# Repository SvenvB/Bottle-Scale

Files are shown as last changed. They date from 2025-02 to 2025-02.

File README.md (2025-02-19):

# BabyBuddy Bottle Scale for Home Assistant
Bottle scale for timing and weighing baby food. The scale is integrated with the Baby Buddy integration in Home Assistant.

* The scale design is inspired by the great work from [sfgabe:](https://github.com/sfgabe/OITProjects/tree/master/BabyBuddy_ESP_HASS), but since I am by far not a woodworking expert, I designed a similar casing in FreeCAD that can be 3D printed. Attached are the files.
* The scale is connected to HomeAssistant via [ESPHome](https://www.home-assistant.io/integrations/esphome/)
* The scale automation is integrated with the NodeRED BabyBuddy project of [tango259](https://github.com/tango2590/baby-buddy)

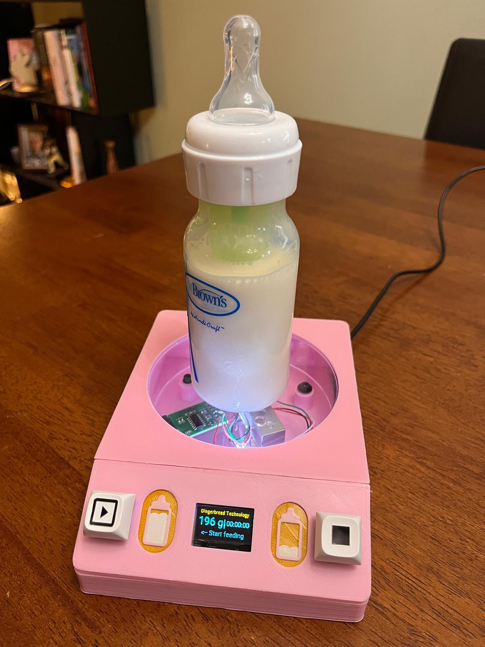
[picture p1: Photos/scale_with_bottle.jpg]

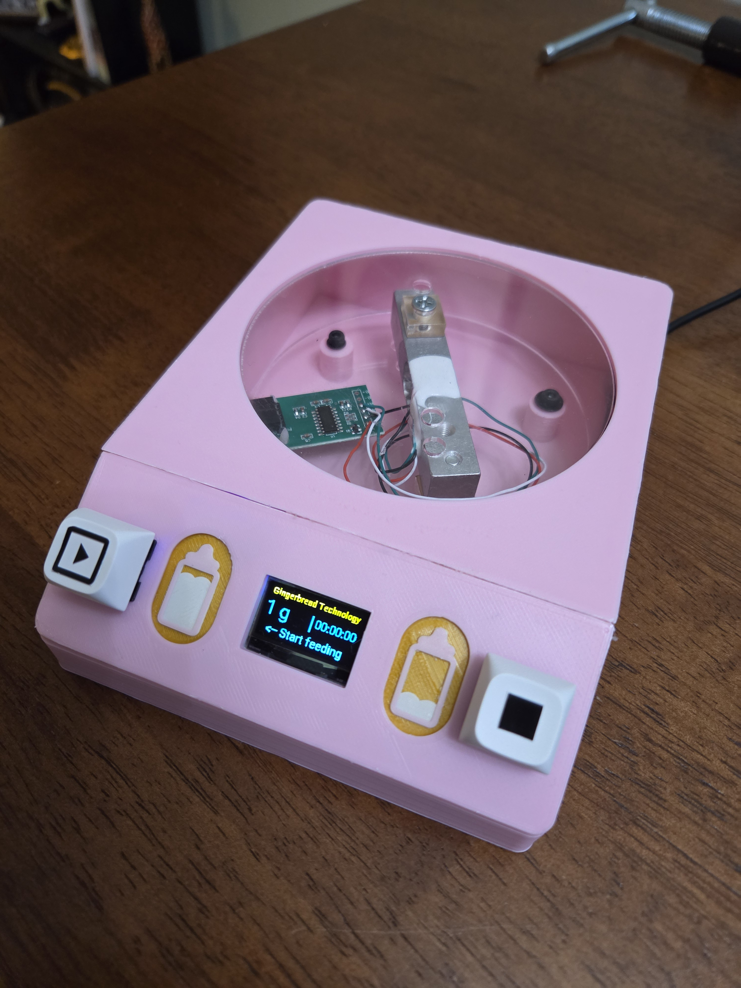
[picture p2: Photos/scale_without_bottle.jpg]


## Ingredients
* 1x [Strain gauge load cell with HX711 amplifier / AD converter](https://www.aliexpress.us/item/3256807921661482.html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). I used a 1 kg capacity load cell, but 5 kg should work also. 
* 1x [Lolin NodeMCU v3 ESP8266 with integrated 0.96" SSD1306 screen](https://www.aliexpress.us/item/3256806790582188.html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). Screen could be bought and connected separately to the microcontroller.
* 2x [Blank Keypad Buttons](https://www.aliexpress.us/item/3256807496928162.html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)
* 2x [Mechanical keyboard switches](https://www.aliexpress.us/item/3256807318817256.html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)
* 3x 5mm through hole LEDs of different colors
* 3x through hole resistors of ~50 Ohm
* (2x M2 screws to fix the microcontroller in the box)
* (3x M3 screws to fix the weighing scale to the box)

## Electrical Connections
* The ESP8266 is getting power from the Vin + GND pins via a USB cable that has a soldered [2x1 female pin header](https://github.com/SvenvB/Bottle-Scale/blob/main/Photos/usb-cable.jpg) to connect to those pins. Using the USB-C connection on the board is not possible because the space is blocked by the push buttons in this CAD design.
* The D8 pin has an internal pull-down resistor, and D8 must be low at boot to avoid boot failure. Therefore, the button connected to D8 should be connected to the +3.3V pin, and not GND. The button connected to D7 makes use of an internal pull-up resistor and is therefore connected to GND.
* The D5 and D6 pins are used by the onboard SSD1306 screen.

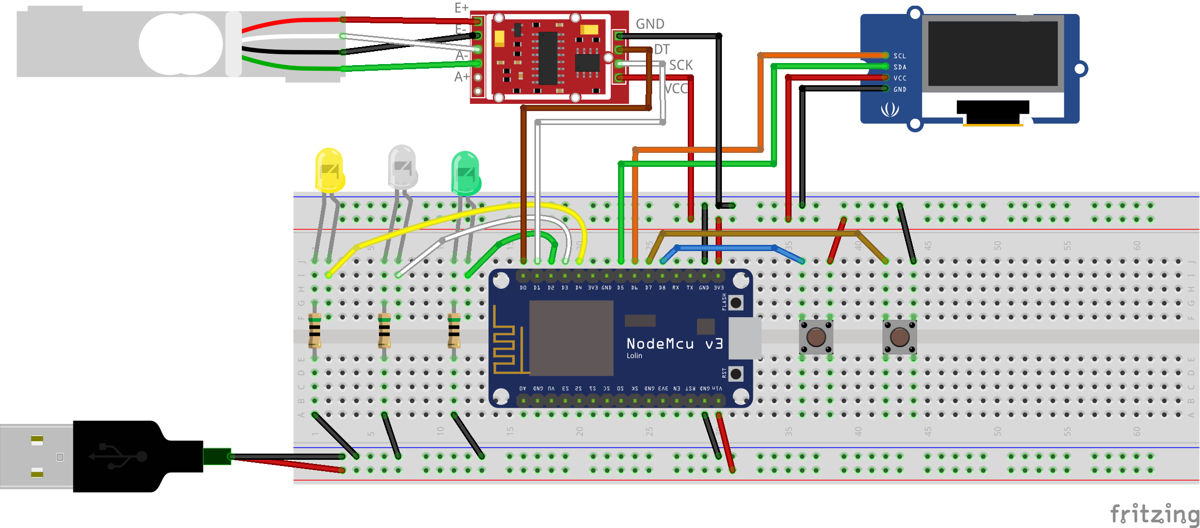
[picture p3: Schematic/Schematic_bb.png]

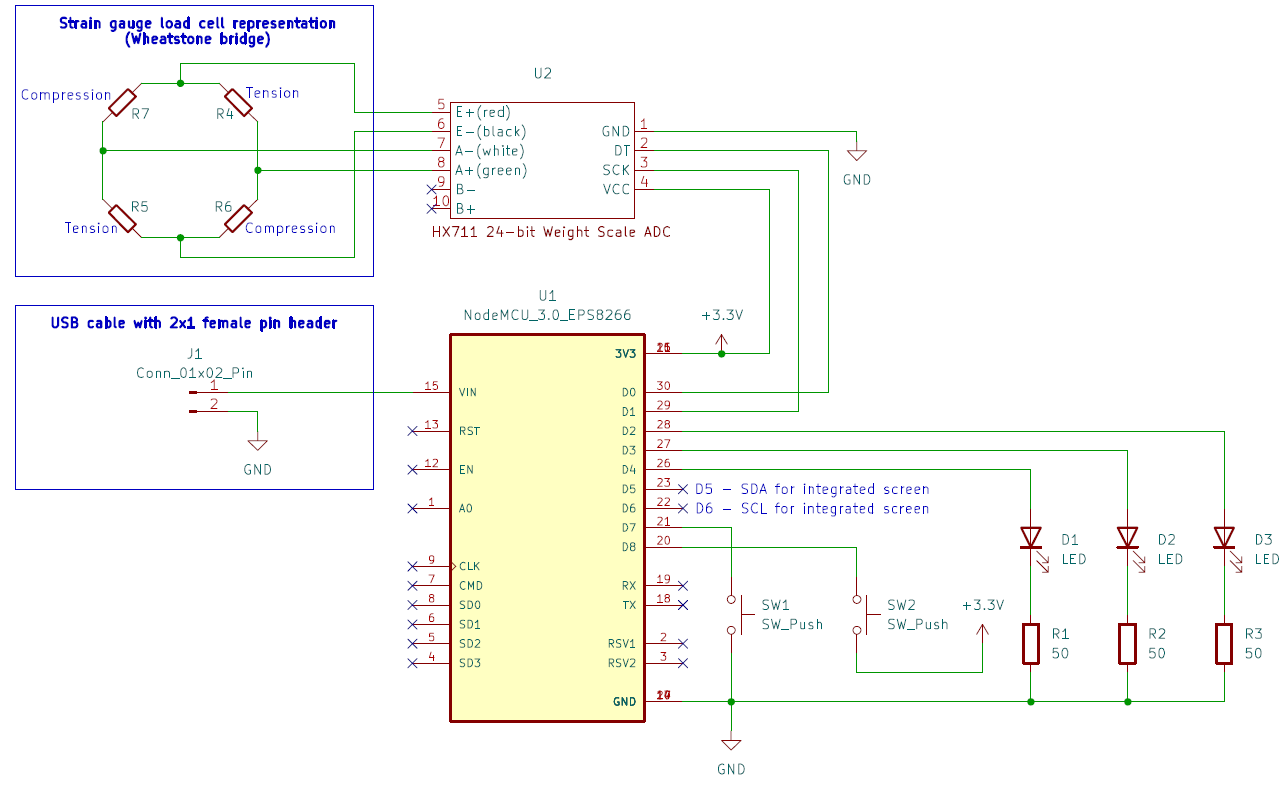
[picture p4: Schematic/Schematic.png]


* The load cell is connected to the HX711 breakout board using 4-wires. Take a moment to familiarize yourself with the basic principle of how a single-point load cell [works](https://www.800loadcel.com/blog/single-point-load-cells-what-they-are-and-how-they-work.html). It relies on 4x strain gauges in a Wheatstone bridge configuration as indicated in the [schematic](https://github.com/SvenvB/Bottle-Scale/blob/main/Schematic/Schematic.png) above. The resistance of those gauges depends on the tension (of the 2x gauges on top) and compression (of the 2x gauges on the bottom) due to the weight applied to the aluminum. Two wires (red [E+] & black [E-]) are used to bias the bridge, whereas the signal potential (Vsignal = [A+] - [A-]) grows with increasing contrast between the tension and compression resistances. The signal is amplified and digitized by the HX711 breakout board. No more to it than that.

## CAD Modeling
* The scale is designed in freeware [FreeCAD](https://www.freecad.org/). Uploaded are the step files but also the FreeCAD project so you can make any changes desired:

**Important notes:**
* The screen location might differ since the screen is manually attached to the board using double-sided tape. Therefore you might need to adjust the CAD model based on your screen location.
* Similarly the mounting holes in the plastic plates of the bottle scale seem to be manually drilled. This also might warrant some manual changes in the CAD model so that your scale fits. The hole in the top plate is a tight fit.
* The electronics compartment is also quite compact. You will want to remove any excessive wire length otherwise it won't fit.
* The top plate and computer plate are not screwed down but glued using a glue pistol. If you don't have a glue pistol or strong double-sided tape, you might want to add some screw holes in the design.   

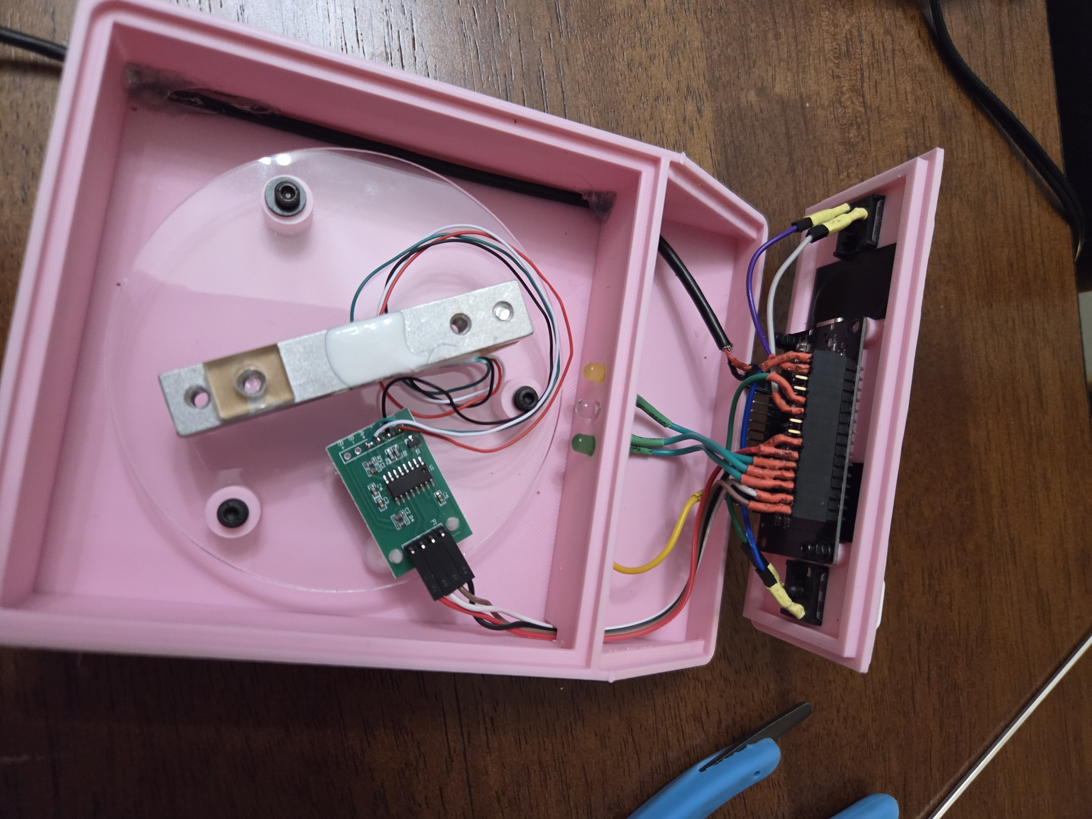
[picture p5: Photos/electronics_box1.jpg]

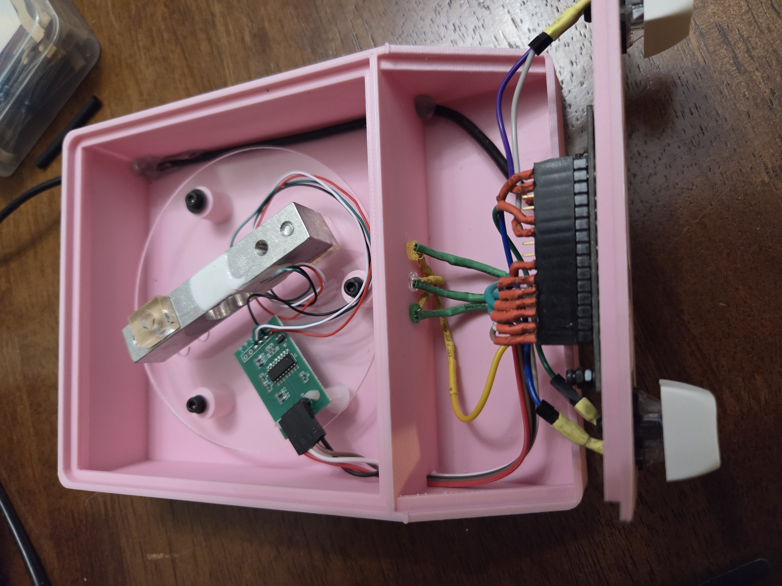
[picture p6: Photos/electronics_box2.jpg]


* The buttons are printed on a 4x6" photo at the local CVS store:

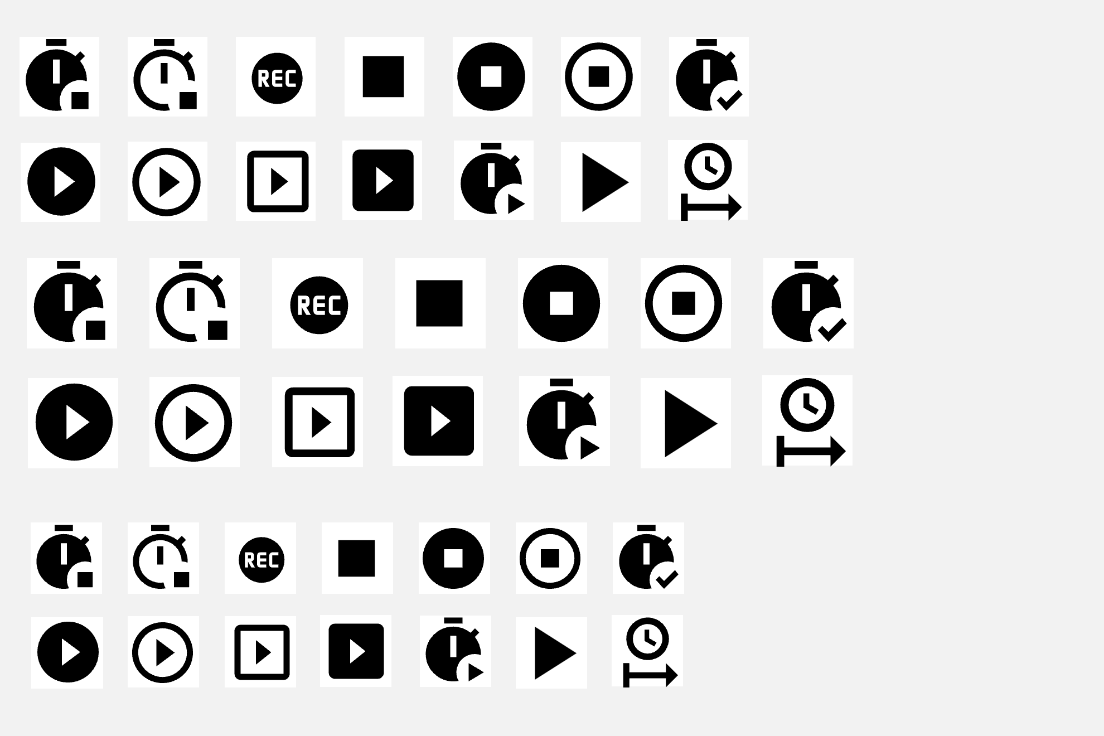
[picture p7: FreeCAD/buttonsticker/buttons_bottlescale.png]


## ESPHome and Automation
I won't go into much detail here, as this can be integrated however you like and I assume that you already have set up BabyBuddy in HomeAssistant. I integrated the automation directly with the NodeRED BabyBuddy project of [tango259](https://github.com/tango2590/baby-buddy).

Attached you can find my [ESPHome code](https://github.com/SvenvB/Bottle-Scale/blob/main/esphome_code.yaml) for the device. The microcontroller receives one sensor and two text_sensors from the home assistant front-end:
* *input_number.bottle_scale_calibration_value*: which is the measured weight when pushing the start button on the left-hand-side. It then subtracts this calibration value from the measured value so that when you put the empty bottle on the scale to stop recording, you can directly see how much the baby ate.
* *sensor.stopwatch*: is the [stopwatch](https://community.home-assistant.io/t/stopwatch-with-start-stop-resume-lap-and-reset/443994) used in the NodeRED BabyBuddy project of [tango259](https://github.com/tango2590/baby-buddy). The stopwatch value is also shown on the screen.
* *input_text.bottle_scale_status*: is a text label on the bottom of the screen that either says *<-- Start feeding*, *Stop feeding-->*, or *Feeding recorded!*.

Don't forget to [calibrate](https://esphome.io/components/sensor/hx711.html) your scale in ESPhome code by removing my calibration and then find the sensor readings when using zero load and a known weight. 

Happy feeding!

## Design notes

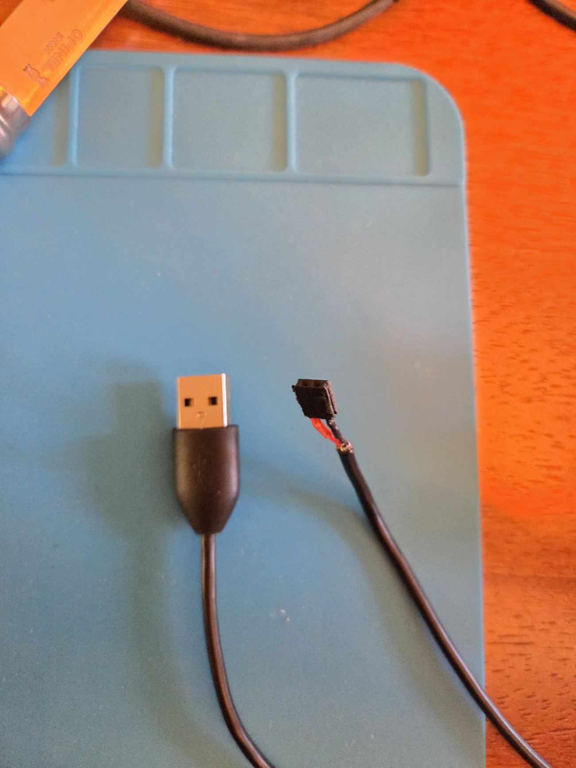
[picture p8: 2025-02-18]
Photos/usb-cable.jpg

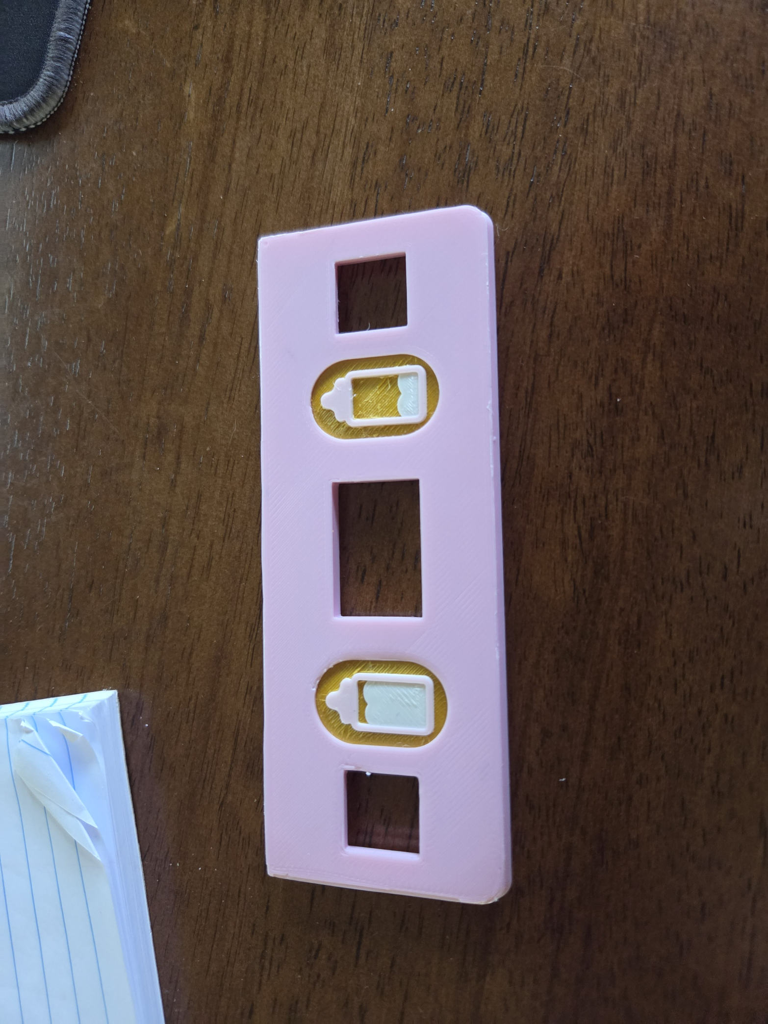
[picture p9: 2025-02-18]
Photos/computer_plate_front.jpg

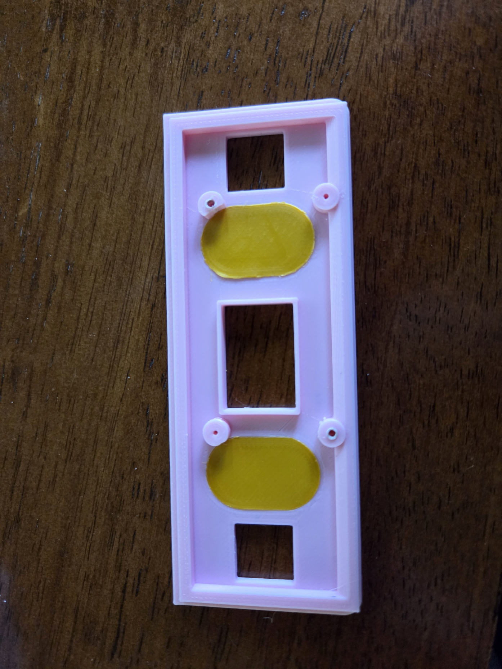
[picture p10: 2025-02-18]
Photos/computer_plate_back.jpg

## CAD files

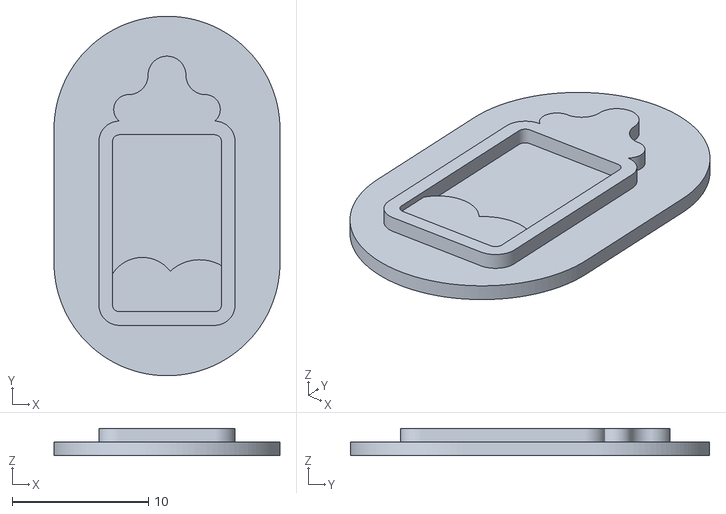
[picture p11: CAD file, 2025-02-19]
FreeCAD/BottleScale-Box AssemblyEmpty bottle.stl
16.6 x 26.4 x 2.00

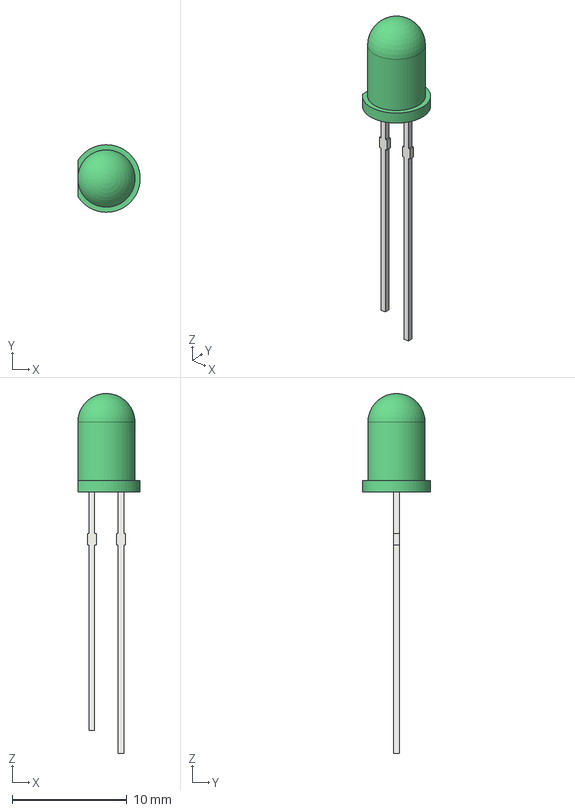
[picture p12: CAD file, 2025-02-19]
FreeCAD/Green Detailed 5mm LED.step
5.45 x 5.90 x 31.4 mm
Glass Round 5mm003
Pin Two MKIII
Pin One MKIII
Bond Wire011

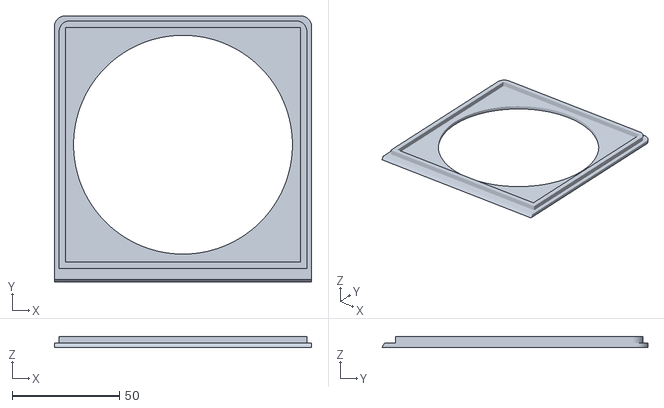
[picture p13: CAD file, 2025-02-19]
FreeCAD/BottleScale-Top plateBody001.stl
120.0 x 124.0 x 5.00

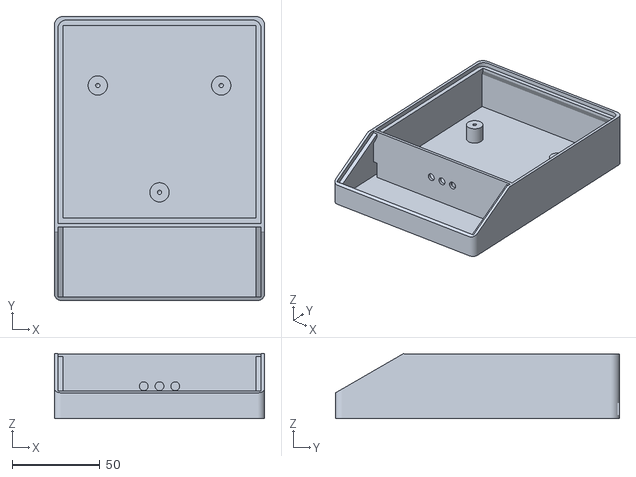
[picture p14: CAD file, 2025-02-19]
FreeCAD/BottleScale-Box.stl
120.0 x 162.0 x 37.2

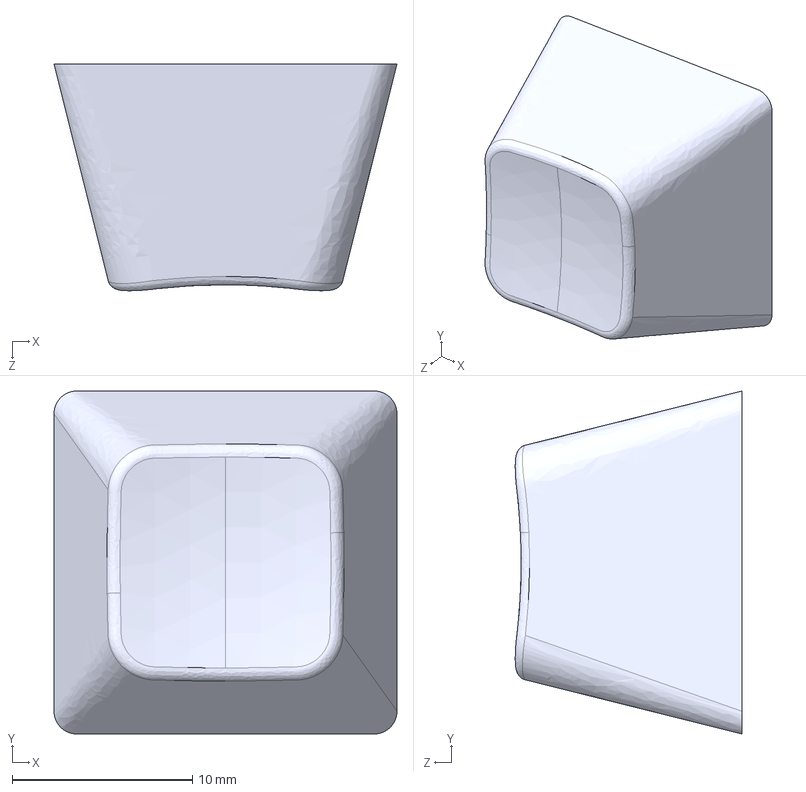
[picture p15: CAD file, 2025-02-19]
FreeCAD/keycap_dsa_signatureplastics_r3.STEP
19.1 x 19.1 x 12.6 mm

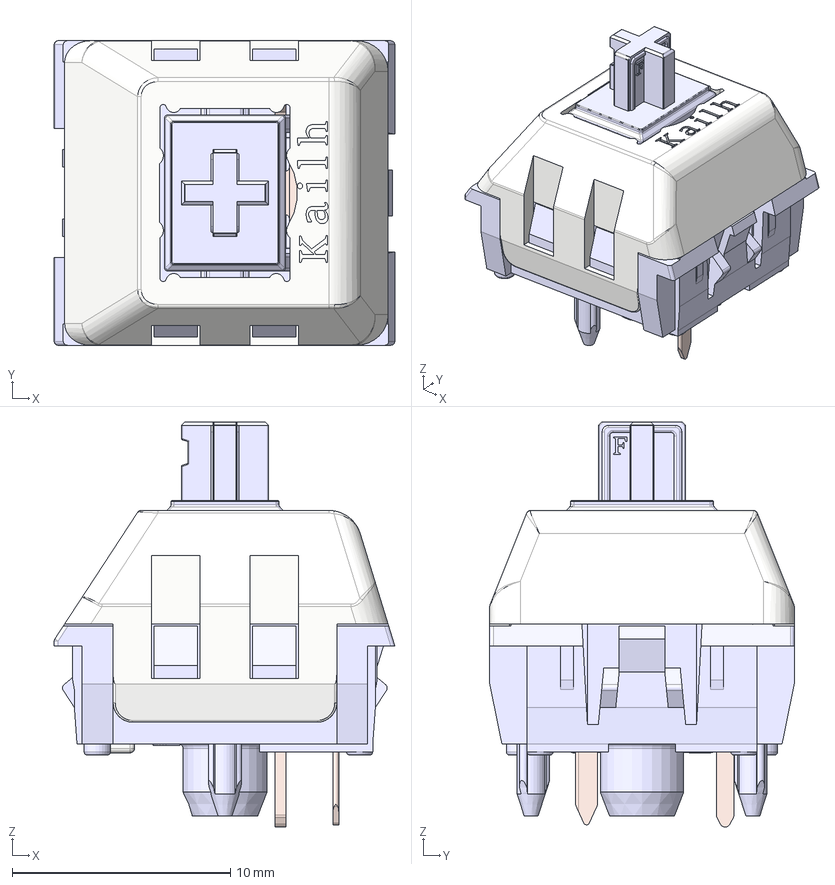
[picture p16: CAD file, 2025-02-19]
FreeCAD/pushbutton.step
15.6 x 14.0 x 18.5 mm
Housing
ThickContact
SpringContact
Stem
Lid

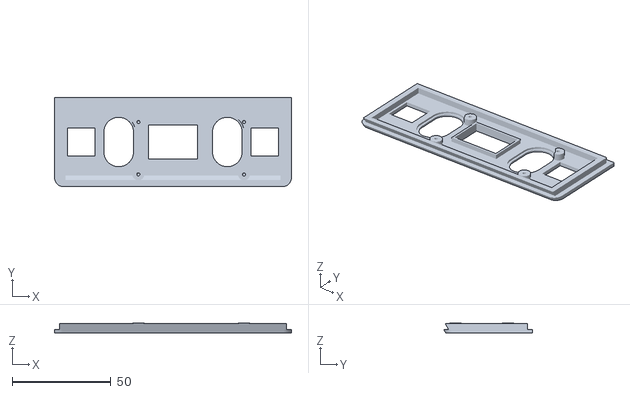
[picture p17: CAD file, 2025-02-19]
FreeCAD/BottleScale-Computer_plate.stl
120.0 x 45.0 x 5.30

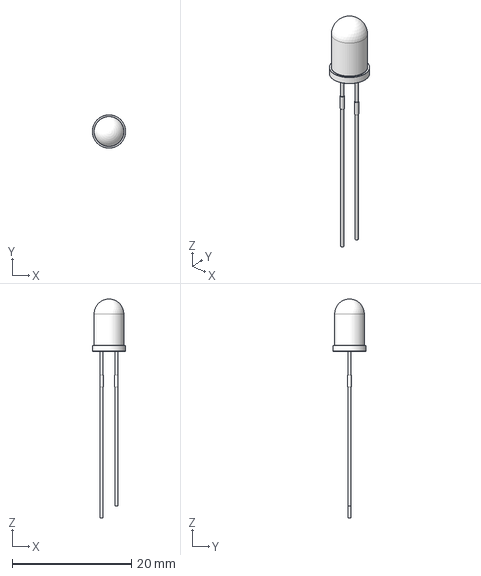
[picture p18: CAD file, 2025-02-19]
FreeCAD/STEP_LED_DIODE_5mm.step
5.59 x 5.60 x 36.8 mm

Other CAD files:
FreeCAD/BottleScale-Box AssemblyFull bottle.stl
FreeCAD/Red Detailed 5mm LED.step

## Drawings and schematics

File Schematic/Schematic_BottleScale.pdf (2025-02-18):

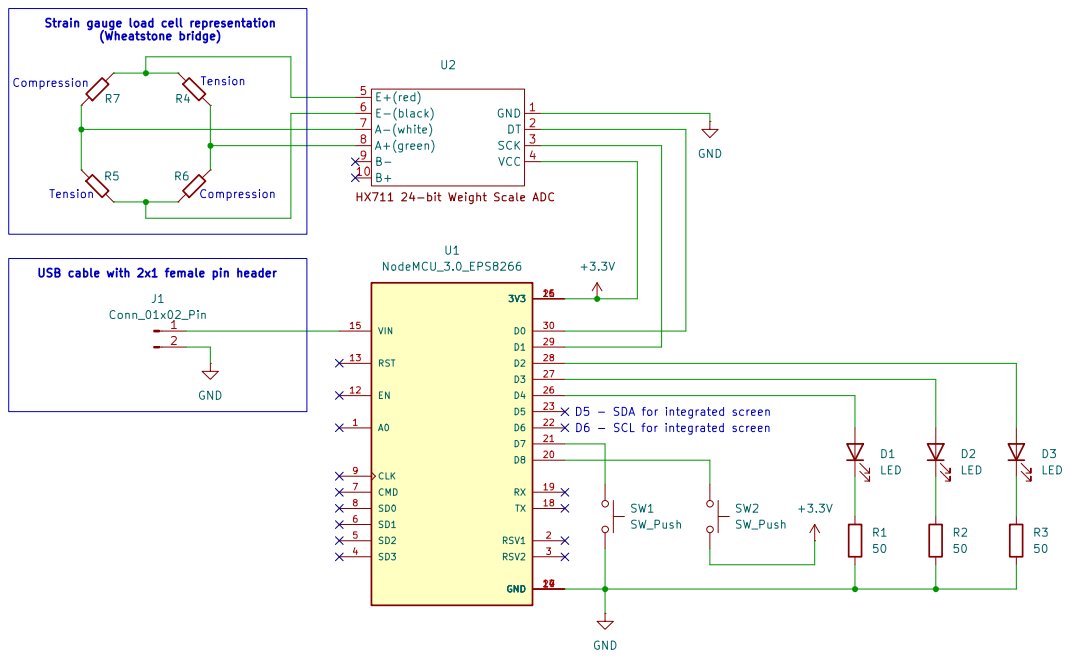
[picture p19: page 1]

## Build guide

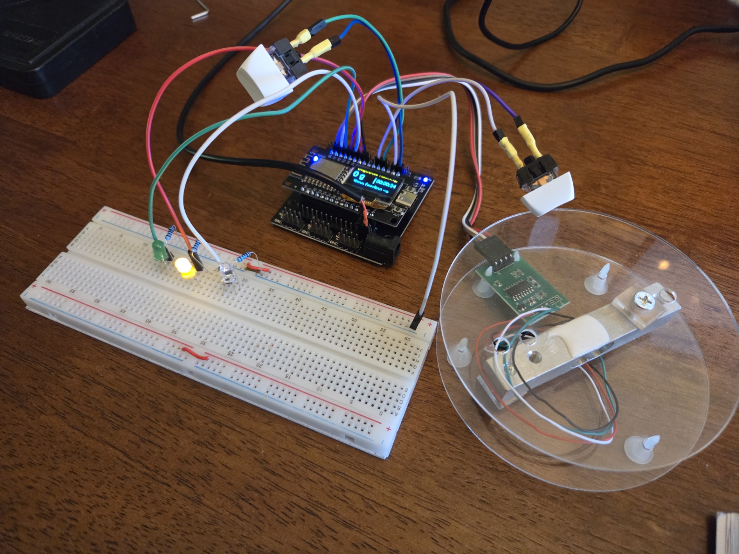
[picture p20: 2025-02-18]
Photos/breadboard_setup.jpg

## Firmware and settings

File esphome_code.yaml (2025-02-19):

esphome:
  name: bottle-scale
  friendly_name: Bottle Scale

esp8266:
  board: nodemcuv2

# Enable logging
logger:
  level: DEBUG  # Keep debug for other components
  logs:
    hx711: WARN  # Suppress detailed HX711 messages

# Enable Home Assistant API
api:
  encryption:
    key: YOURAPIKEY

ota:
  - platform: esphome
    password: YOUROTAPASS

wifi:
  ssid: !secret wifi_ssid
  password: !secret wifi_password

  # Enable fallback hotspot (captive portal) in case wifi connection fails
  ap:
    ssid: "Bottle-Scale Fallback Hotspot"
    password: PASS

captive_portal:

# Status LEDs
switch:
  - platform: gpio
    pin: D2
    name: "Bottle scale status LED - Green"
    id: LED_green
  - platform: gpio
    pin: D4
    name: "Bottle scale status LED - Yellow"
    id: LED_yellow
  - platform: gpio
    pin: D3
    name: "Bottle scale status LED - White"
    id: LED_white        

# Font definitions
font:
  - file: "gfonts://Roboto"
    id: title_font
    size: 11
  - file: "gfonts://Roboto"
    id: meas_font
    size: 25
  - file: "gfonts://Roboto"
    id: time_font
    size: 15    
# I2C Configuration for HW364A OLED
i2c:
  sda: D5
  scl: D6
  scan: true # Enable to detect I2C devices
  frequency: 400kHz

# OLED Display Configuration
display:
  - platform: ssd1306_i2c
    model: "SSD1306 128X64"
    address: 0x3C
    id: hw364a_display
    pages:
      - id: page1
        lambda: |-
          // Print "Gingerbread Technology" on the first line, centered
          const char *title = "Gingerbread Technology";
          int title_width = strlen(title) * 5.5;  // Estimate character width (adjust if needed)
          int title_x = (128 - title_width) / 2;  // Center horizontally
          it.print(title_x, 0, id(title_font), title);

          // Get and round the weight value
          if (id(bottle_scale_cal_value).has_state()) {
              float cal_value = id(bottle_scale_cal_value).state;  // Get calibration value
              int weight = abs(round(id(bottle_scale_sensor).state - cal_value));
              char buffer[10];
              sprintf(buffer, "%d g", weight);  // Format weight as "123 g"

              // Print weight value on the left side
              it.print(0, 12, id(meas_font), buffer);
          }

          // Draw a vertical centerline (2-pixel width)
          int x_center = 128 / 2;
          it.line(x_center, 20, x_center, 40);
          it.line(x_center + 1, 20, x_center + 1, 40);

          // Print stopwatch time on the right-hand side
          if (id(stopwatch_sensor).has_state()) {
              std::string stopwatch_time = id(stopwatch_sensor).state;

              // Find the '.' character (milliseconds separator)
              size_t dot_position = stopwatch_time.find('.');

              // If milliseconds exist, remove them by truncating the string
              if (dot_position != std::string::npos) {
                  stopwatch_time = stopwatch_time.substr(0, dot_position);
              }

              // Estimate text width based on characters (adjust as needed)
              int text_width = stopwatch_time.length() * 7.0;
              int text_x = 128 - text_width - 2;  // Align to the right side

              it.print(text_x, 20, id(time_font), stopwatch_time.c_str());
          }


          // Print calibration status below the timer
          if (id(bottle_scale_status).has_state()) {
            std::string bottle_scale_cal_status = id(bottle_scale_status).state;

            // Estimate text width based on characters (adjust as needed)
            int text_width = bottle_scale_cal_status.length() * 6.5;
            int text_x = (128 - text_width) / 2;  // Align in the center

            it.print(text_x, 45, id(time_font), bottle_scale_cal_status.c_str());
          }          
       



sensor:
  - platform: hx711     # HX711 24-bit ADC for weight scale
    name: "Bottle Scale sensor"
    id: bottle_scale_sensor 
    dout_pin: D0
    clk_pin: D1
    gain: 128
    update_interval: 0.2s
    device_class: weight
    state_class: "measurement"
    unit_of_measurement: g
    accuracy_decimals: 0
    icon: mdi:weight-gram
    filters:
      - calibrate_linear:
        - 65000 -> 0
        - 557688 -> 784
      - sliding_window_moving_average:
          window_size: 5
          send_every: 5        
  - platform: homeassistant   #  Calibration value
    id: bottle_scale_cal_value
    entity_id: input_number.bottle_scale_calibration_value

# Import the stopwatch from home assistant as text sensor
text_sensor:
  - platform: homeassistant
    id: stopwatch_sensor
    entity_id: sensor.stopwatch  
  - platform: homeassistant
    id: bottle_scale_status
    entity_id: input_text.bottle_scale_status
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

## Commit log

2025-02-18 Added schematic files
2025-02-18 Update README.md
    Added schematic figures
2025-02-18 Added another schematic picture
2025-02-18 Changed schematic from pdf to png
2025-02-19 Added CAD files
    [BottleScale-Box AssemblyEmpty bottle.stl, BottleScale-Box AssemblyFull bottle.stl, BottleScale-Box.stl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]
